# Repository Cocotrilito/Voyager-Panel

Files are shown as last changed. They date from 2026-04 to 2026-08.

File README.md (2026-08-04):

<div align="center">

# ⟡ VOYAGER PANEL ⟡

### An E-Ink travel dashboard

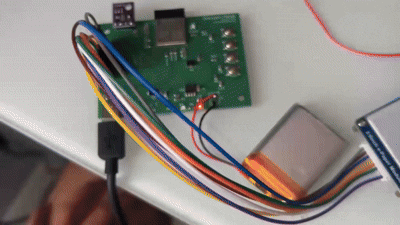
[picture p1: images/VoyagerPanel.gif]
Voyager Panel in motion


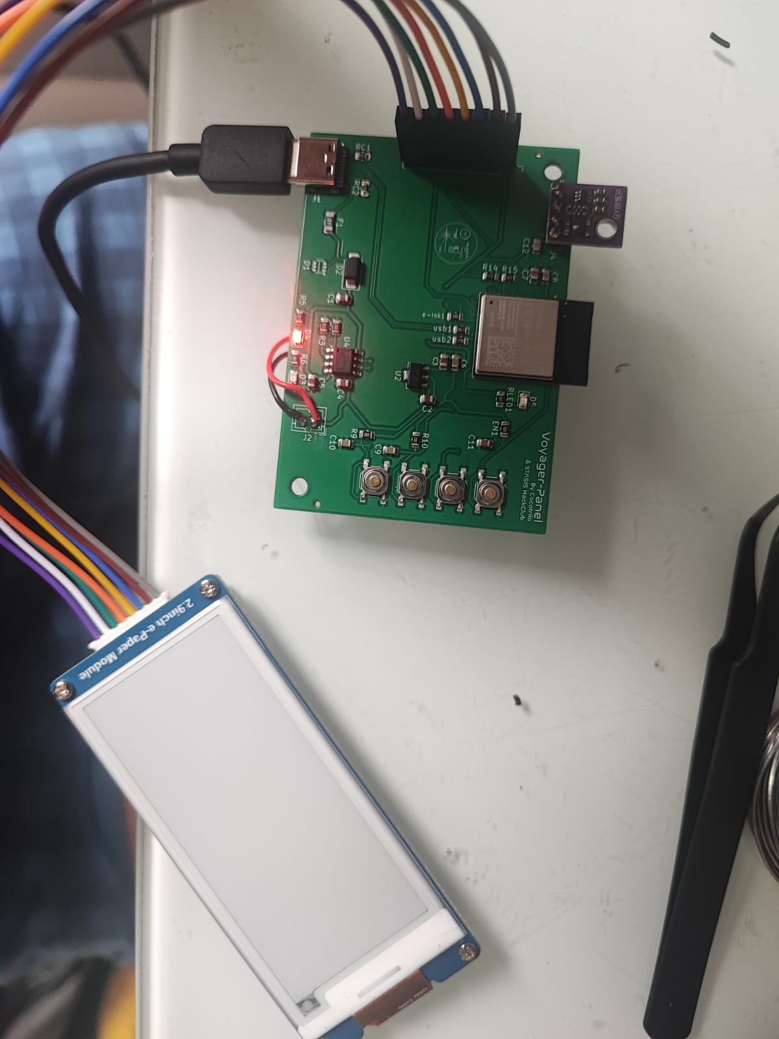
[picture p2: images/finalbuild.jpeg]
Final build


`ESP32-S3` · `296×128 E-Paper` · `Battery Powered` · `Wi-Fi` · `Low Power`

</div>

---

An E-Ink travel dashboard. with an ESP32-S3 Showing weather, hackclub countdowns, and travel info for hackactons. this dashboard has Low-Power consumption, Wi-Fi connected, battery-operated!!!!

---

## ⟡ The reason behind this project

This project started from the *dream* of always wanting to have a big countdown telling you the Narrow door for a better future is closing, yeah crazy right?, hahaha well actually this project started in the supermarket of my local city, I was shopping and noticed an E-Ink display, I thought *I have seen this before* and it was when I was searching my first project I saw something called E-Ink dashboard, and was cool but I thought Im too newbie for this, so I challenged myself to improve my PCB designer skills and I think I did a really cool project, im really proud of it tbh, well but in the end the actual big reason is to truly have a giant countdown telling you stasis is over in X days or telling you your youth days are over in X days I love presure >:D

---

## ⟡ Schematic Overview

<div align="center">

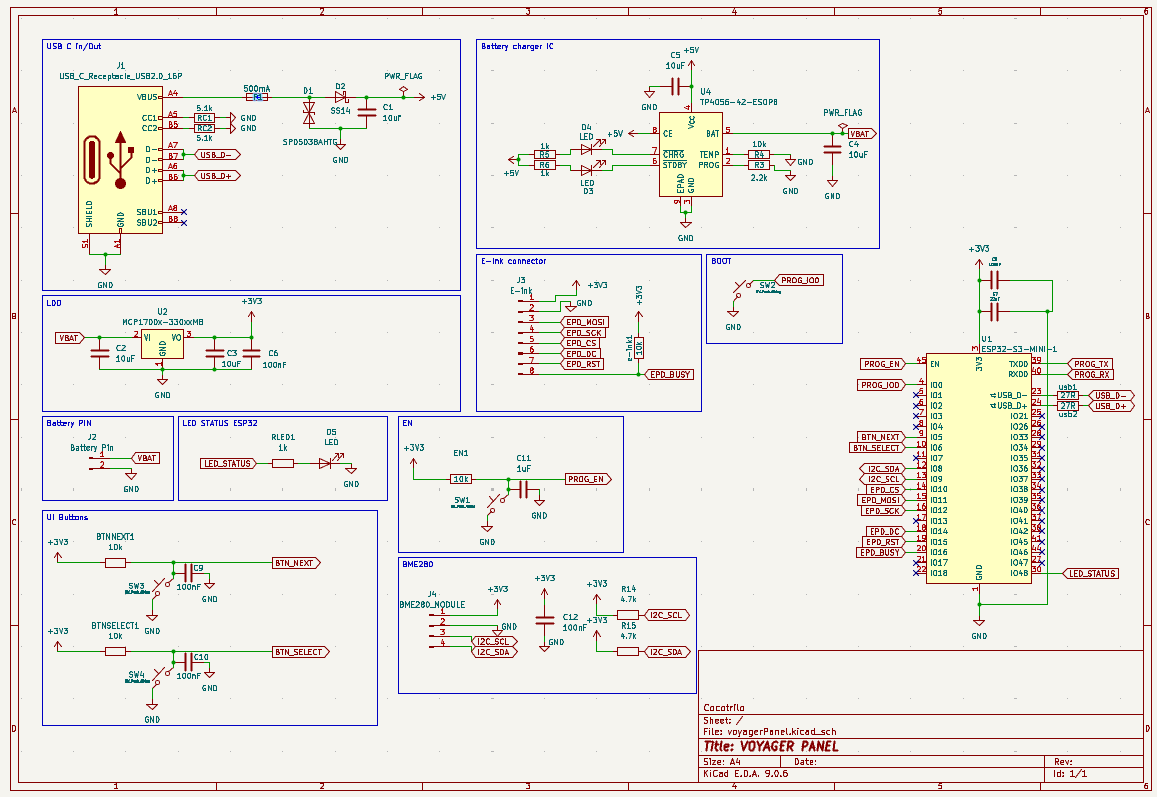
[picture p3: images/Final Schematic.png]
Schematic


</div>

---

## ⟡ PCB — DIFFERENT VERSIONS

<div align="center">

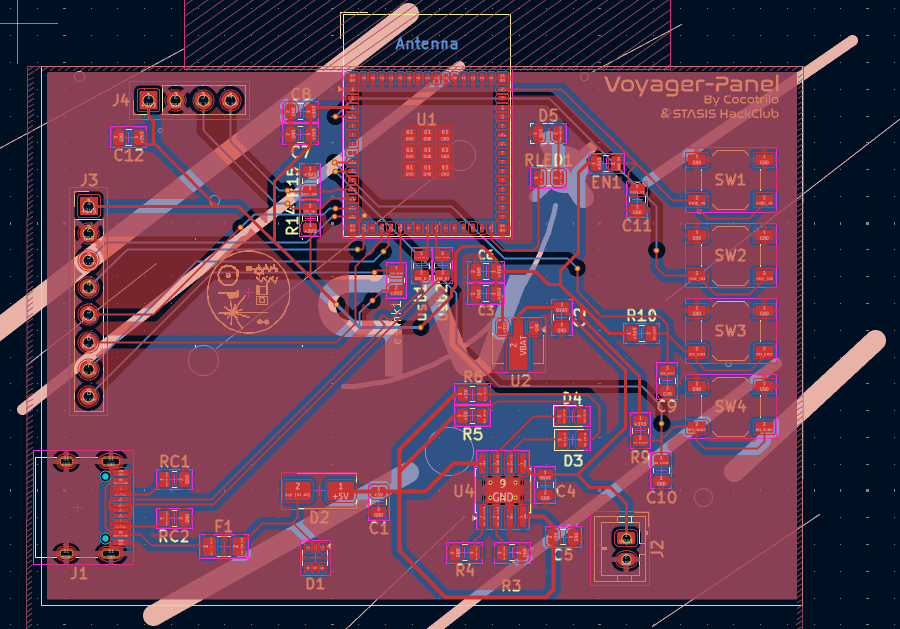
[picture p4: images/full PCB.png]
PCB


</div>

<table>
<tr>
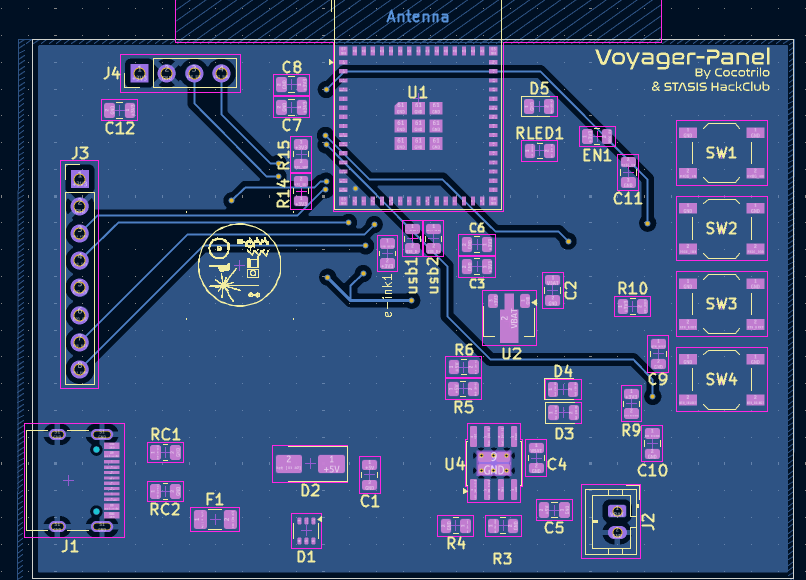
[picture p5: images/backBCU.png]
B.Cu layer
<td width="50%"></td>
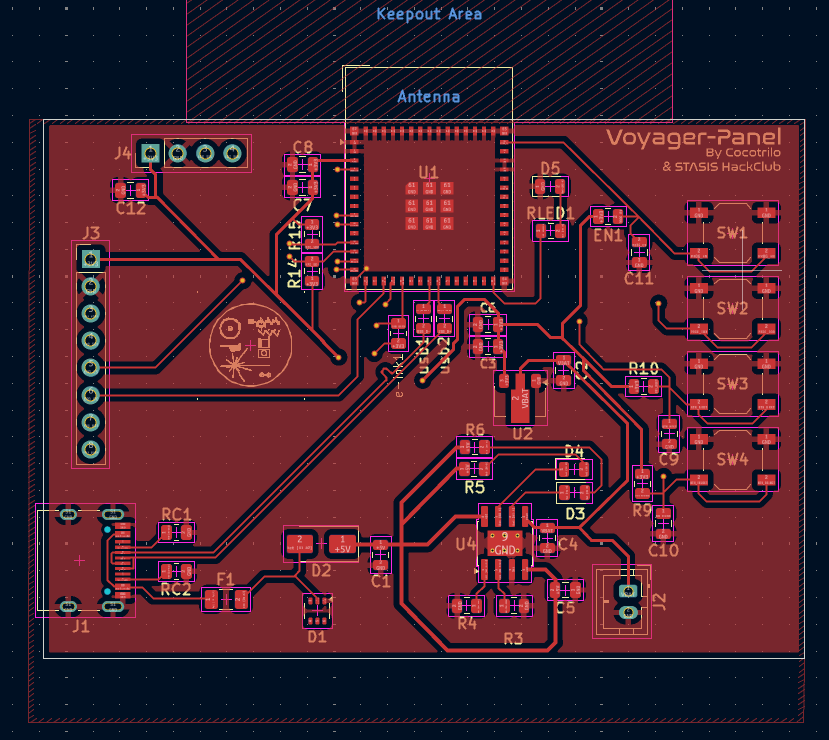
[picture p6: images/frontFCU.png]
F.Cu layer
<td width="50%"></td>
</tr>
<tr>
<td align="center"><b>Back copper</b></td>
<td align="center"><b>Front copper</b></td>
</tr>
</table>

---

## ⟡ RENDER!!

<div align="center">

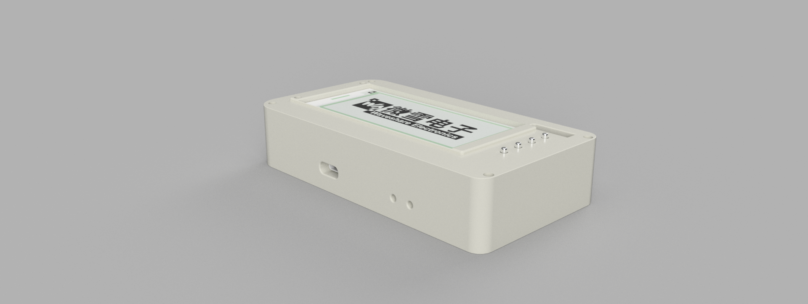
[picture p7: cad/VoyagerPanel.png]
RenderFusion


</div>

<table>
<tr>
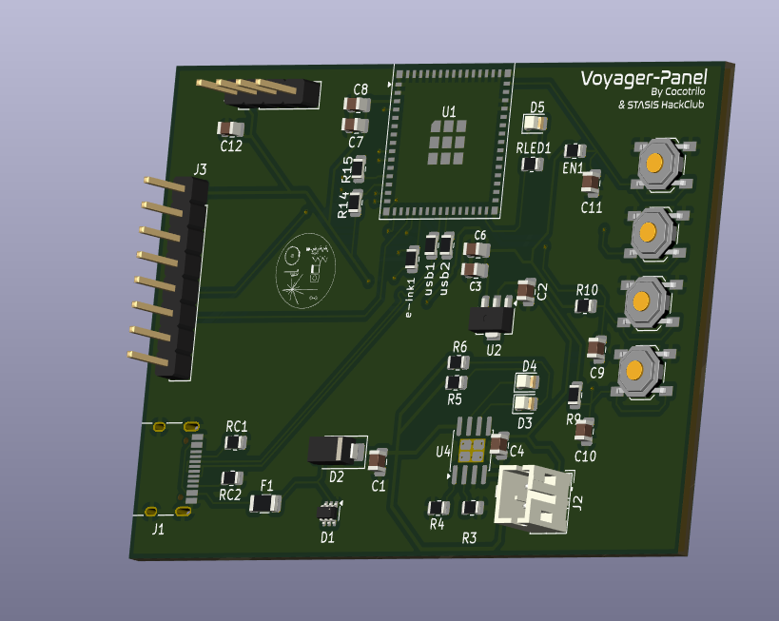
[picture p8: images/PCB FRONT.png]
PCB front
<td width="50%"></td>
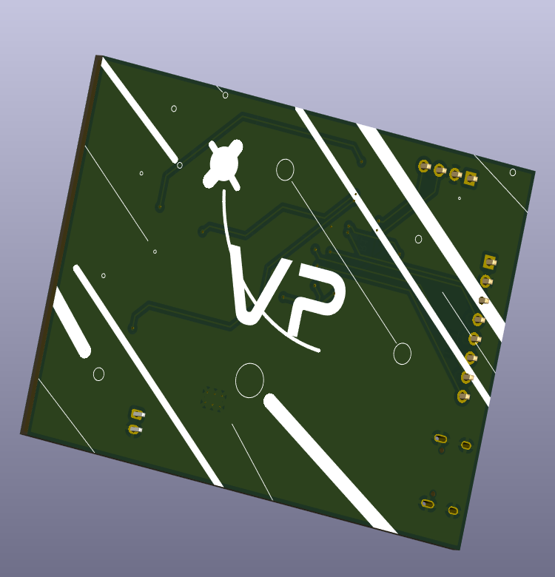
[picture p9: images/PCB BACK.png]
PCB back
<td width="50%"></td>
</tr>
<tr>
<td align="center"><b>Front</b></td>
<td align="center"><b>Back</b></td>
</tr>
</table>

---

## ⟡ Hardware at a glance

| | |
|---|---|
| **MCU** | ESP32-S3-MINI-1 — Wi-Fi, BLE, native USB |
| **Display** | Waveshare 2.9" e-Paper, 296×128, SSD1680 controller |
| **Sensor** | BMP280 over I2C — temperature, pressure, derived altitude |
| **Power** | 1000 mAh LiPo, TP4056 charger, MCP1700 LDO |
| **Protection** | TVS ESD array, Schottky reverse-current diode, 500 mA polyfuse |
| **Programming** | Native USB-C, no external UART bridge |

---

## ⟡ Firmware

Built with **PlatformIO** on the Arduino framework.

```
firmware/VoyagerPanelFirmware/
├── platformio.ini
└── src/
    ├── main.cpp
    └── images.h
```

Because the board uses the ESP32-S3's native USB and carries no USB-UART bridge,
`Serial` has to be routed to the USB CDC peripheral. Without these flags nothing
reaches the host:

```ini
build_flags =
    -D ARDUINO_USB_MODE=1
    -D ARDUINO_USB_CDC_ON_BOOT=1
```

The sensor and the display initialise **independently**, so a failure in one does not
take down the other. The dashboard degrades gracefully instead of hanging.

### Live telemetry

```
========== VOYAGER SENSOR ==========
  Temperature : 29.29 C
  Pressure    : 751.36 hPa
  Altitude    : 2452.2 m
====================================
```

---

## ⟡ Debugging log

The display refused to render, and tracking down why turned into the most interesting
part of this build — a full diagnosis of a hardware fault carried out **without a
multimeter**, using the microcontroller itself as the measuring instrument.

Short version: the SSD1680 was running on **phantom power**, leaking current through
its own ESD protection diodes. Enough to acknowledge a reset, not enough to execute a
single SPI command.

The full write-up, including the software continuity matrix used to prove it, lives in
**[DEBUGGING.md](DEBUGGING.md)**.

A second find along the way: the module sold as a BME280 is actually a **BMP280**. Its
chip ID register returns `0x58` instead of `0x60`, and it has no humidity channel. The
firmware reads that register and picks the right driver rather than trusting the label.

---

## ⟡ BOM

| Name | Purpose | Qty | Cost (USD) | Distributor |
|---|---|-----|---|---|
| ESP32-S3-MINI-1 | Main microcontroller with WiFi and USB native | 1 | $8.50 | AliExpress |
| Waveshare 2.9inch e-Paper Module | Main e-ink display 296x128px | 1 | $17.00 | AliExpress |
| BME280 Breakout Module | Temperature/Humidity/Pressure sensor | 1 | $5.15 | AliExpress |
| LiPo Battery 1000mAh 3.7V | Portable power source | 1 | $5.00 | Local Ecuador |
| USB-C Receptacle 16P | Power input and native USB programming | 1 | $0.50 | JLCPCB |
| JST PH 2mm 2-Pin Connector | Battery connector | 1 | $0.10 | JLCPCB |
| Pin Header 1x08 2.54mm | E-ink display connector | 1 | $0.05 | Local |
| Pin Header 1x04 2.54mm | BME280 module connector | 1 | $0.05 | Local |
| TP4056-42-ESOP8 | LiPo battery charger IC | 1 | $0.15 | JLCPCB |
| MCP1700-3302 SOT-89 | 3.3V LDO regulator 0.2V dropout | 1 | $0.45 | JLCPCB |
| SP0503BAHTG SOT-363 | TVS ESD protection diode for USB | 1 | $0.20 | JLCPCB |
| SS14 SMA | Schottky diode reverse current protection | 1 | $0.05 | JLCPCB |
| Polyfuse 500mA 1206 | Resettable overcurrent fuse | 1 | $0.10 | JLCPCB |
| SW_SPST_TL3342 | Tactile buttons Reset/Boot/Next/Select | 4 | $0.05 | JLCPCB |
| LED 0805 Red | Battery charging indicator CHRG | 1 | $0.02 | JLCPCB |
| LED 0805 Blue | Standby indicator STDBY | 1 | $0.02 | JLCPCB |
| LED 0805 Green | System status indicator | 1 | $0.02 | JLCPCB |
| Resistor 1k 0805 | LED current limiting resistors | 3 | $0.03 | JLCPCB |
| Resistor 2.2k 0805 | TP4056 charge current set 550mA | 1 | $0.01 | JLCPCB |
| Resistor 4.7k 0805 | I2C SDA/SCL pull-up resistors | 2 | $0.02 | JLCPCB |
| Resistor 5.1k 0805 | USB-C CC1/CC2 pull-down resistors | 2 | $0.02 | JLCPCB |
| Resistor 10k 0805 | Pull-ups for EN/BOOT/UI buttons | 5 | $0.05 | JLCPCB |
| Resistor 27R 0805 | USB D+/D- series termination | 2 | $0.02 | JLCPCB |
| Capacitor 100nF 0805 | High frequency decoupling | 5 | $0.05 | JLCPCB |
| Capacitor 1uF 0805 | EN pin reset debounce | 1 | $0.02 | JLCPCB |
| Capacitor 10uF 0805 | Bulk decoupling capacitors | 5 | $0.15 | JLCPCB |
| Capacitor 22uF 0805 | ESP32 main power bulk decoupling | 1 | $0.05 | JLCPCB |
| PCB + SMT Assembly | 2-layer PCB with PCBA | 1 | $47.90 | JLCPCB |
| **TOTAL** | | | **$85.42** | |

---

## ⟡ Repository layout

```
├── cad/                          Fusion 360 enclosure + renders
├── docs/references/              Datasheets and reference material
├── firmware/
│   ├── VoyagerPanelFirmware/     PlatformIO project
│   └── diagnostics/              Hardware bring-up test sketches
├── images/                       Schematic, PCB, and build photos
├── projectFiles/
├── voyagerPanel/                 KiCad project
├── DEBUGGING.md
└── README.md
```

---

## ⟡ Final notes!

Thanks for reading! made possible with http://stasis.hackclub.com/

---

<div align="center">

## ⟡ me

*By cocotrilo*

**made with luv (THIS ONE was with a lot of love, EXCEPT FOR THE BOM PLEASE DONT USE EVER ALIEXPRESS) Nk but luv from EC <3**

</div>

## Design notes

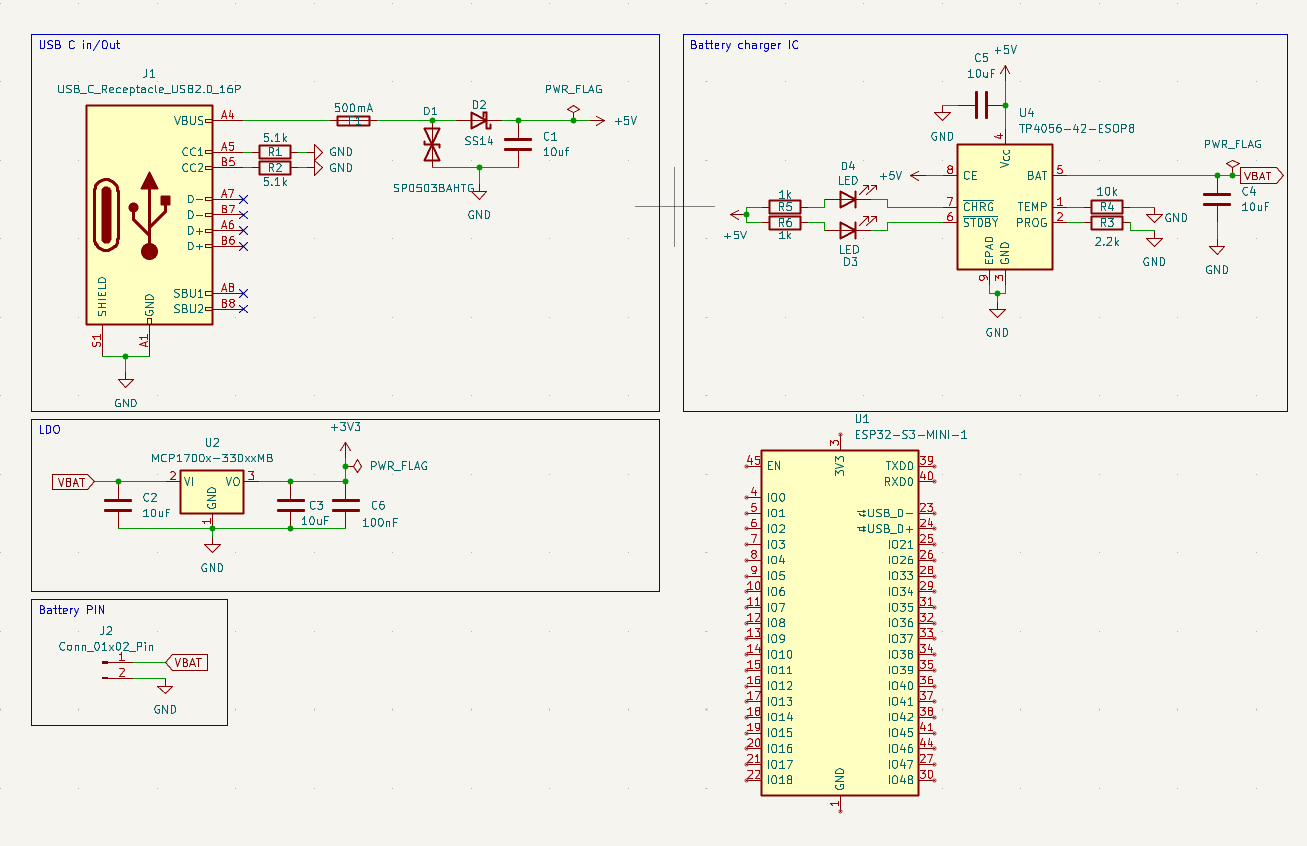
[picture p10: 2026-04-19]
images/Day 1 schematic.png

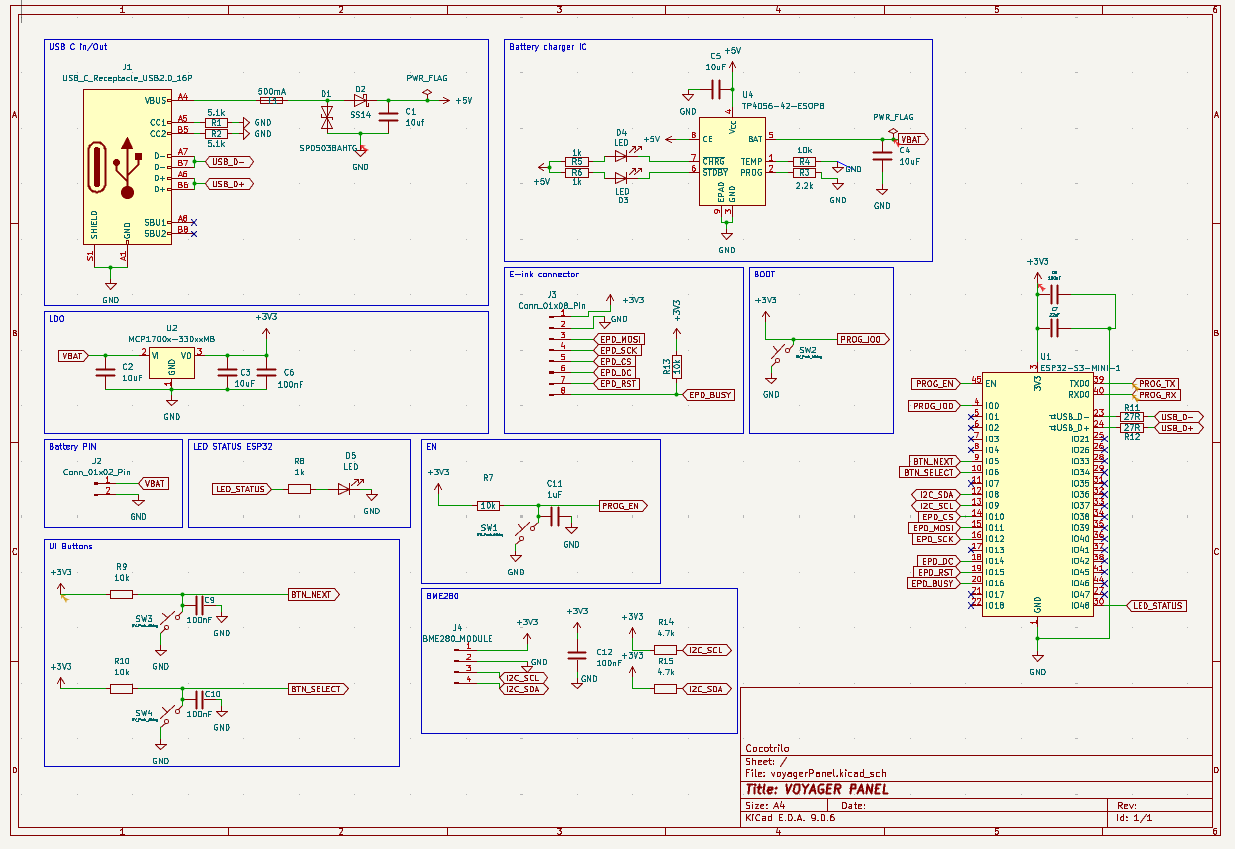
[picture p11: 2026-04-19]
images/Day Schematic.png

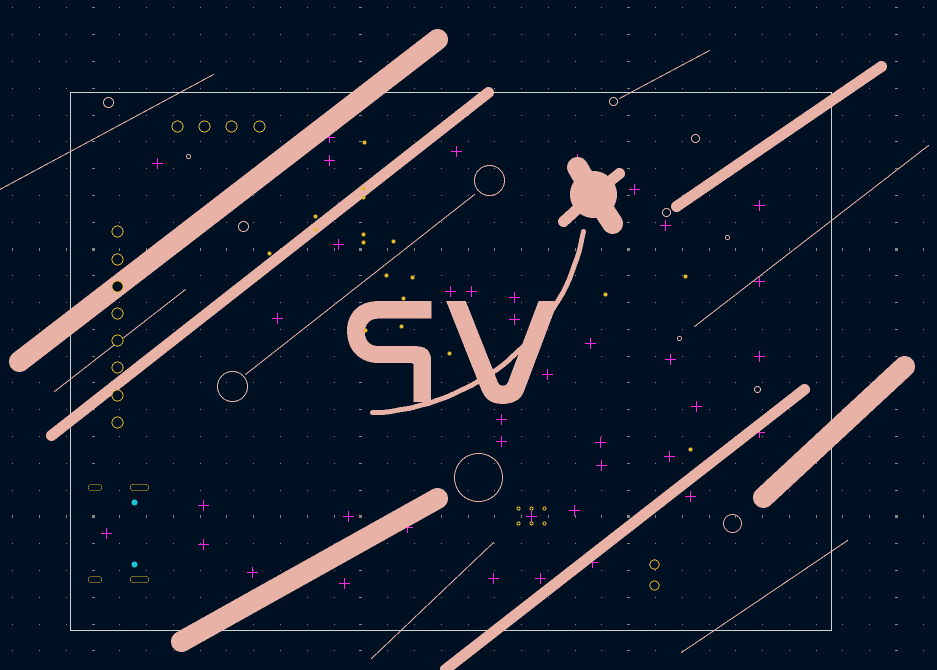
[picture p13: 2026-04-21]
images/back.png

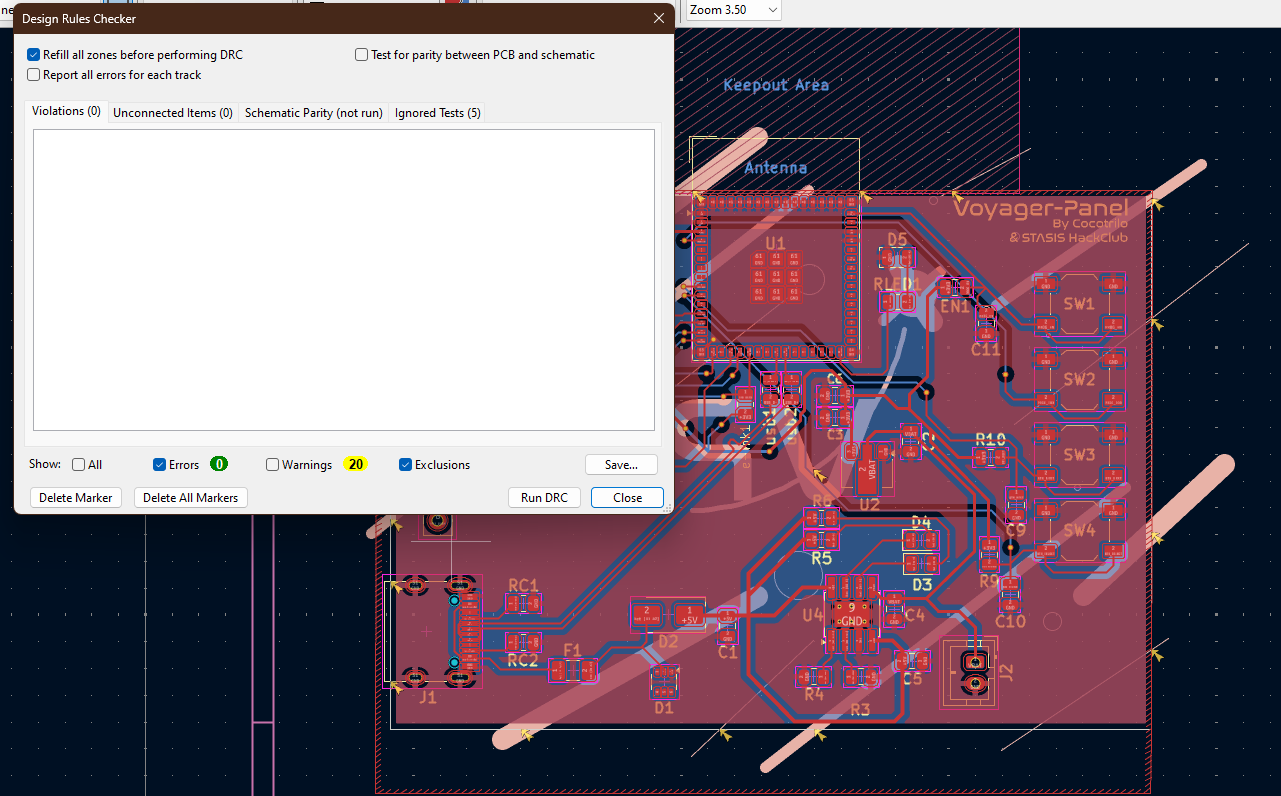
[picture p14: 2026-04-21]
images/DRC.png

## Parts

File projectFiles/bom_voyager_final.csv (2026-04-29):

Name | Purpose | Quantity | Unit Cost (USD) | Total Cost (USD) | Distributor | Link
ESP32-S3-MINI-1 | Main microcontroller with WiFi and USB native | 1 | $8.50 | $8.50 | AliExpress | https://www.aliexpress.com/item/ESP32-S3-MINI-1.html
Waveshare 2.9inch e-Paper Module | Main e-ink display 296x128px | 1 | $17.00 | $17.00 | AliExpress | https://www.waveshare.com/2.9inch-e-paper-module.htm
BME280 Breakout Module | Temperature/Humidity/Pressure sensor | 1 | $5.15 | $5.15 | AliExpress | https://www.aliexpress.us/item/3256805961500122.html
LiPo Battery 1000mAh 3.7V | Portable power source - bought locally | 1 | $5.00 | $5.00 | Local Ecuador | N/A
USB-C Receptacle 16P | Power input and native USB programming | 1 | $0.50 | $0.50 | JLCPCB/LCSC | https://www.lcsc.com/product-detail/C165948.html
JST PH 2mm 2-Pin Connector | Battery connector | 1 | $0.10 | $0.10 | JLCPCB/LCSC | https://www.lcsc.com/product-detail/C295747.html
Pin Header 1x08 2.54mm | E-ink display connector | 1 | $0.05 | $0.05 | Local/AliExpress | N/A
Pin Header 1x04 2.54mm | BME280 module connector | 1 | $0.05 | $0.05 | Local/AliExpress | N/A
TP4056-42-ESOP8 | LiPo battery charger IC up to 550mA | 1 | $0.15 | $0.15 | JLCPCB/LCSC | https://www.lcsc.com/product-detail/C16581.html
MCP1700-3302 SOT-89 | 3.3V LDO regulator 0.2V dropout | 1 | $0.45 | $0.45 | JLCPCB/LCSC | https://www.lcsc.com/product-detail/C5446.html
SP0503BAHTG SOT-363 | TVS ESD protection diode for USB | 1 | $0.20 | $0.20 | JLCPCB/LCSC | https://www.lcsc.com/product-detail/C558442.html
SS14 SMA | Schottky diode reverse current protection | 1 | $0.05 | $0.05 | JLCPCB/LCSC | https://www.lcsc.com/product-detail/C2480.html
Polyfuse 500mA 1206 | Resettable overcurrent fuse | 1 | $0.10 | $0.10 | JLCPCB/LCSC | https://www.lcsc.com/product-detail/C69688.html
SW_SPST_TL3342 x4 | Tactile buttons - Reset/Boot/Next/Select | 4 | $0.05 | $0.20 | JLCPCB/LCSC | https://www.lcsc.com/product-detail/C2886894.html
LED 0805 Red | Battery charging indicator (CHRG) | 1 | $0.02 | $0.02 | JLCPCB/LCSC | https://www.lcsc.com/product-detail/C84256.html
LED 0805 Blue | Standby indicator (STDBY) | 1 | $0.02 | $0.02 | JLCPCB/LCSC | https://www.lcsc.com/product-detail/C72041.html
LED 0805 Green | System status indicator | 1 | $0.02 | $0.02 | JLCPCB/LCSC | https://www.lcsc.com/product-detail/C72043.html
Resistor 1k 0805 x3 | LED current limiting resistors | 3 | $0.01 | $0.03 | JLCPCB/LCSC | https://www.lcsc.com/product-detail/C17513.html
Resistor 2.2k 0805 | TP4056 charge current set (~550mA) | 1 | $0.01 | $0.01 | JLCPCB/LCSC | https://www.lcsc.com/product-detail/C17520.html
Resistor 4.7k 0805 x2 | I2C SDA/SCL pull-up resistors | 2 | $0.01 | $0.02 | JLCPCB/LCSC | https://www.lcsc.com/product-detail/C17673.html
Resistor 5.1k 0805 x2 | USB-C CC1/CC2 pull-down resistors | 2 | $0.01 | $0.02 | JLCPCB/LCSC | https://www.lcsc.com/product-detail/C23186.html
Resistor 10k 0805 x5 | Pull-ups for EN/BOOT/UI buttons | 5 | $0.01 | $0.05 | JLCPCB/LCSC | https://www.lcsc.com/product-detail/C17414.html
Resistor 27R 0805 x2 | USB D+/D- series termination resistors | 2 | $0.01 | $0.02 | JLCPCB/LCSC | https://www.lcsc.com/product-detail/C17719.html
Capacitor 100nF 0805 x5 | High frequency decoupling capacitors | 5 | $0.01 | $0.05 | JLCPCB/LCSC | https://www.lcsc.com/product-detail/C49678.html
Capacitor 1uF 0805 | EN pin reset debounce capacitor | 1 | $0.02 | $0.02 | JLCPCB/LCSC | https://www.lcsc.com/product-detail/C28323.html
Capacitor 10uF 0805 x5 | Bulk decoupling capacitors | 5 | $0.03 | $0.15 | JLCPCB/LCSC | https://www.lcsc.com/product-detail/C15850.html
Capacitor 22uF 0805 | ESP32 main power bulk decoupling | 1 | $0.05 | $0.05 | JLCPCB/LCSC | https://www.lcsc.com/product-detail/C45783.html
PCB Manufacturing x5 | Custom 2-layer PCB with SMT assembly | 1 | $47.90 | $47.90 | JLCPCB | https://jlcpcb.com
TOTAL |  |  |  | ~$85.42

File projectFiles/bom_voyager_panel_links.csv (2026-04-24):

Name | Purpose | Quantity | Unit Cost (USD) | Total Cost (USD) | Distributor | Link
ESP32-S3-MINI-1 | Main microcontroller with WiFi | 1 | $8.5 | $8.5 | LCSC | https://www.lcsc.com/product-detail/C2913202.html
Waveshare 4.2inch e-Paper Module | Main e-ink display 400x300px | 1 | $18.00 | $18.00 | Waveshare | https://www.waveshare.com/4.2inch-e-paper-module.htm
BME280 Breakout Module | Temperature/Humidity/Pressure sensor | 1 | $5.15 | $5.15 | AliExpress | https://www.aliexpress.us/item/3256805961500122.html?mp=1
LiPo Battery 1000mAh 3.7V | Portable power source | 1 | $5.00 | $5.00 | AliExpress
USB-C Receptacle 16P | Power input and native USB programming | 1 | $0.50 | $0.50 | LCSC | https://www.lcsc.com/product-detail/C165948.html
JST PH 2mm 2-Pin Connector | Battery connector | 1 | $0.10 | $0.10 | LCSC | https://www.lcsc.com/product-detail/C295747.html
Pin Header 1x08 2.54mm | E-ink display connector | 1 | $0.05 | $0.05 | LCSC | https://www.lcsc.com/product-detail/C2337.html
Pin Header 1x04 2.54mm | BME280 module connector | 1 | $0.03 | $0.03 | LCSC | https://www.lcsc.com/product-detail/C2336.html
TP4056-42-ESOP8 | LiPo battery charger IC | 1 | $0.15 | $0.15 | LCSC | https://www.lcsc.com/product-detail/C16581.html
MCP1700-3302 SOT-89 | 3.3V LDO regulator 0.2V dropout | 1 | $0.45 | $0.45 | LCSC | https://www.lcsc.com/product-detail/C5446.html
SP0503BAHTG SOT-363 | TVS ESD protection diode | 1 | $0.20 | $0.20 | LCSC | https://www.lcsc.com/product-detail/C558442.html
SS14 SMA | Schottky reverse protection diode | 1 | $0.05 | $0.05 | LCSC | https://www.lcsc.com/product-detail/C2480.html
Polyfuse 500mA 1206 | Resettable overcurrent fuse | 1 | $0.10 | $0.10 | LCSC | https://www.lcsc.com/product-detail/C69688.html
SW_SPST_TL3342 x4 | Tactile push buttons (Reset/Boot/Next/Select) | 4 | $0.05 | $0.20 | LCSC | https://www.lcsc.com/product-detail/C2886894.html
LED 0805 Red | Battery charging indicator | 1 | $0.02 | $0.02 | LCSC | https://www.lcsc.com/product-detail/C84256.html
LED 0805 Blue | Standby indicator | 1 | $0.02 | $0.02 | LCSC | https://www.lcsc.com/product-detail/C72041.html
LED 0805 Green | System status indicator | 1 | $0.02 | $0.02 | LCSC | https://www.lcsc.com/product-detail/C72043.html
Resistor 1k 0805 x3 | LED current limiting | 3 | $0.01 | $0.03 | LCSC | https://www.lcsc.com/product-detail/C17513.html
Resistor 2.2k 0805 | TP4056 charge current set | 1 | $0.01 | $0.01 | LCSC | https://www.lcsc.com/product-detail/C17520.html
Resistor 4.7k 0805 x2 | I2C SDA/SCL pull-ups | 2 | $0.01 | $0.02 | LCSC | https://www.lcsc.com/product-detail/C17673.html
Resistor 5.1k 0805 x2 | USB-C CC1/CC2 pull-downs | 2 | $0.01 | $0.02 | LCSC | https://www.lcsc.com/product-detail/C23186.html
Resistor 10k 0805 x5 | Pull-ups EN/BOOT/buttons | 5 | $0.01 | $0.05 | LCSC | https://www.lcsc.com/product-detail/C17414.html
Resistor 27R 0805 x2 | USB D+/D- series resistors | 2 | $0.01 | $0.02 | LCSC | https://www.lcsc.com/product-detail/C17719.html
Capacitor 100nF 0805 x5 | Decoupling capacitors | 5 | $0.01 | $0.05 | LCSC | https://www.lcsc.com/product-detail/C49678.html
Capacitor 1uF 0805 | EN pin debounce | 1 | $0.02 | $0.02 | LCSC | https://www.lcsc.com/product-detail/C28323.html
Capacitor 10uF 0805 x5 | Bulk decoupling | 5 | $0.03 | $0.15 | LCSC | https://www.lcsc.com/product-detail/C15850.html
Capacitor 22uF 0805 | ESP32 main bulk decoupling | 1 | $0.05 | $0.05 | LCSC | https://www.lcsc.com/product-detail/C45783.html
PCB Manufacturing x5 | Custom 2-layer PCB 70x50mm | 5 | $5.00 | $5.00 | JLCPCB | https://jlcpcb.com
PCB Assembly PCBA | SMT assembly for SMD components | 1 | $17.00 | $17.00 | JLCPCB | https://jlcpcb.com
TOTAL |  |  |  | $59-62

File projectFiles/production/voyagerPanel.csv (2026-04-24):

Id | Designator | Footprint | Quantity | Comment | Supplier and ref
1 | C3,C4,C2,C5 | C_0805_2012Metric | 4 | 10uF
2 | R6,R5,RLED1 | R_0805_2012Metric | 3 | 1k
3 | F1 | Fuse_1206_3216Metric | 1 | 500mA
4 | J3 | PinHeader_1x08_P2.54mm_Vertical | 1 | E-ink
5 | RC2,RC1 | R_0805_2012Metric | 2 | 5.1k
6 | SW3,SW4,SW2,SW1 | SW_SPST_TL3342 | 4 | SW_Push_45deg
7 | C1 | C_0805_2012Metric | 1 | 10uf
8 | C7 | C_0805_2012Metric | 1 | 22uF
9 | C11 | C_0805_2012Metric | 1 | 1uF
10 | D5,D4,D3 | LED_0805_2012Metric | 3 | LED
11 | R9,R4,R10,e-ink1,EN1 | R_0805_2012Metric | 5 | 10k
12 | J1 | USB_C_Receptacle_HRO_TYPE-C-31-M-12 | 1 | USB_C_Receptacle_USB2.0_16P
13 | C9,C8,C12,C10,C6 | C_0805_2012Metric | 5 | 100nF
14 | usb1,usb2 | R_0805_2012Metric | 2 | 27R
15 | D2 | D_SMA | 1 | SS14
16 | U4 | SOIC-8-1EP_3.9x4.9mm_P1.27mm_EP2.41x3.3mm_ThermalVias | 1 | TP4056-42-ESOP8
17 | J2 | JST_PH_B2B-PH-K_1x02_P2.00mm_Vertical | 1 | Battery Pin
18 | U2 | SOT-89-3 | 1 | MCP1700x-330xxMB
19 | J4 | PinHeader_1x04_P2.54mm_Vertical | 1 | BME280_MODULE
20 | R3 | R_0805_2012Metric | 1 | 2.2k
21 | R14,R15 | R_0805_2012Metric | 2 | 4.7k
22 | D1 | SOT-363_SC-70-6 | 1 | SP0503BAHTG
23 | U1 | ESP32-S2-MINI-1 | 1 | ESP32-S3-MINI-1

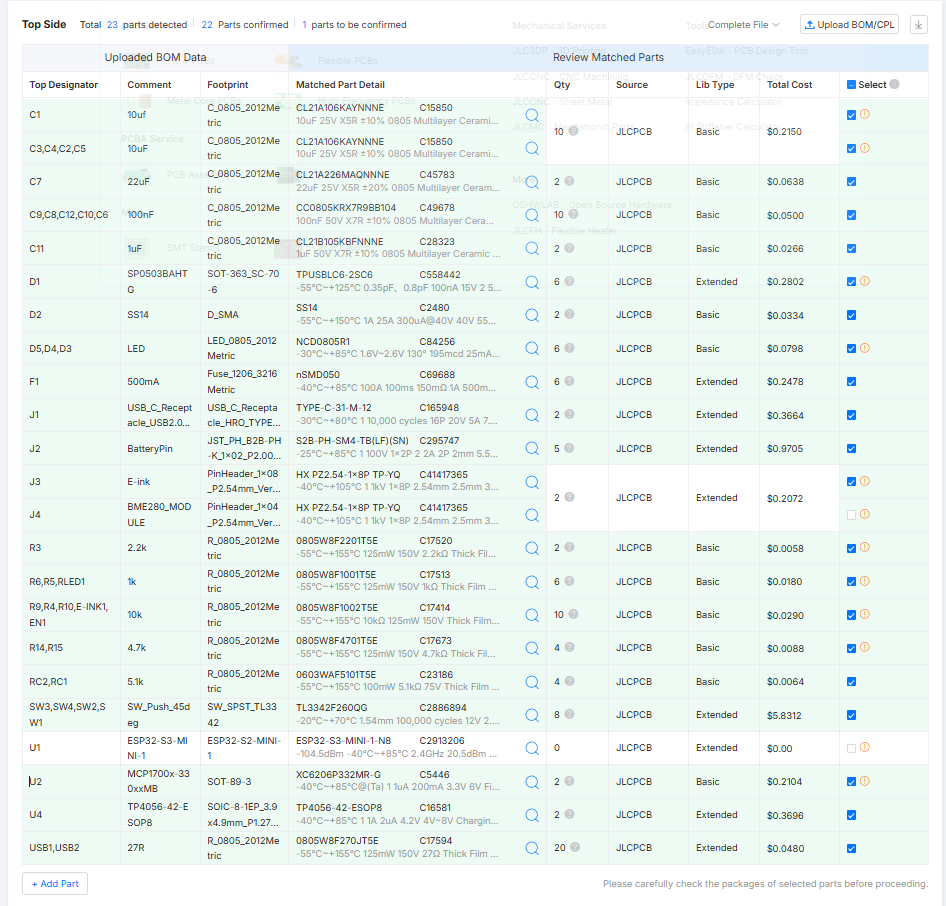
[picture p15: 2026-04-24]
images/BOM JLCPCB.png

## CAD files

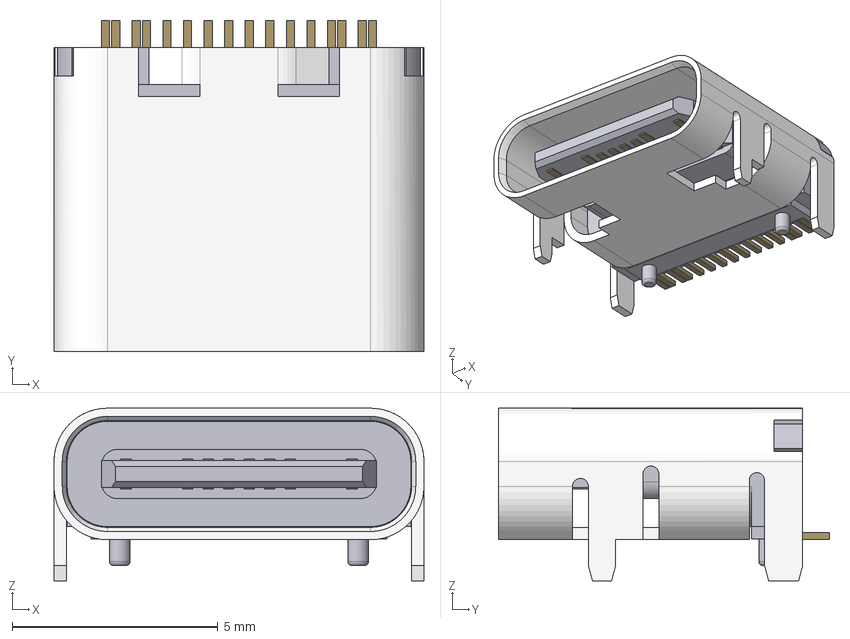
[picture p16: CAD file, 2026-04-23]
cad/MODELS/16-pin-smd-usb-c-connector-through-holes-1.snapshot.7/usb-c_16pins_vertical.step
9.00 x 8.05 x 4.20 mm
tongue
shield
contact_001
contact_002
contact_003
contact_004
contact_court_001
contact_court_002
contact_court_003
contact_court_004
contact_005
contact_006
contact_007
contact_008
contact_court_005
contact_court_006
contact_court_007
contact_court_008
pin_001
pin_002
pin_003
pin_004
pin_005
pin_006
pin_007
pin_008
pin_009
pin_010
pin_011
pin_012
pin_013
pin_014
pin_015
pin_016

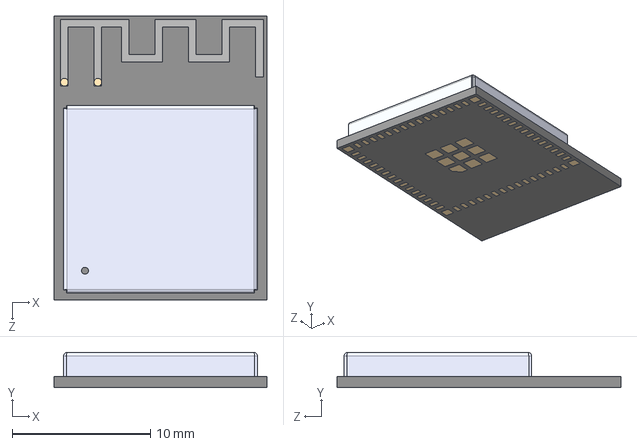
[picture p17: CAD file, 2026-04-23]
cad/MODELS/ESP32_S3_MINI_1_N8/ESP32-S3-MINI-1-N8.STEP
15.4 x 2.55 x 20.5 mm

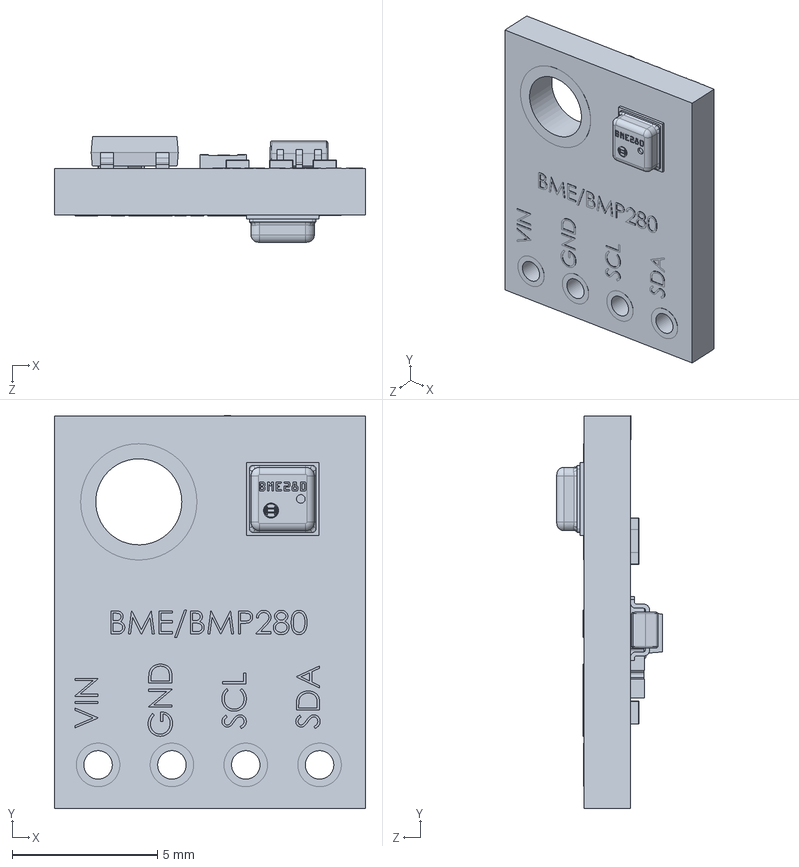
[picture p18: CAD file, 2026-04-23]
cad/MODELS/gy-bme280-1.snapshot.4/GY-BME280.SLDPRT
10.7 x 13.5 x 3.63 mm

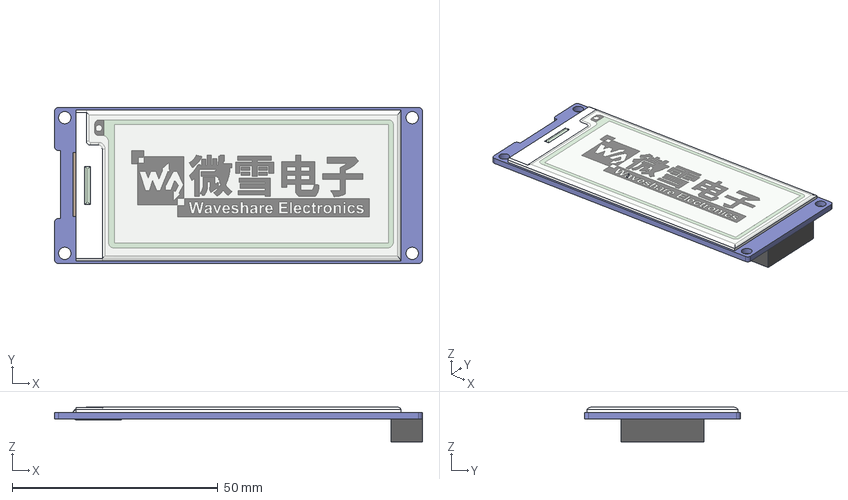
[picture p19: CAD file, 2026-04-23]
cad/MODELS/waveshare-2-9-e-paper-module-1.snapshot.1/Waveshare 2.9 epaper module.step
89.5 x 38.0 x 8.47 mm
pcb
Waveshare 2.9 E-ink - Display Folded v1

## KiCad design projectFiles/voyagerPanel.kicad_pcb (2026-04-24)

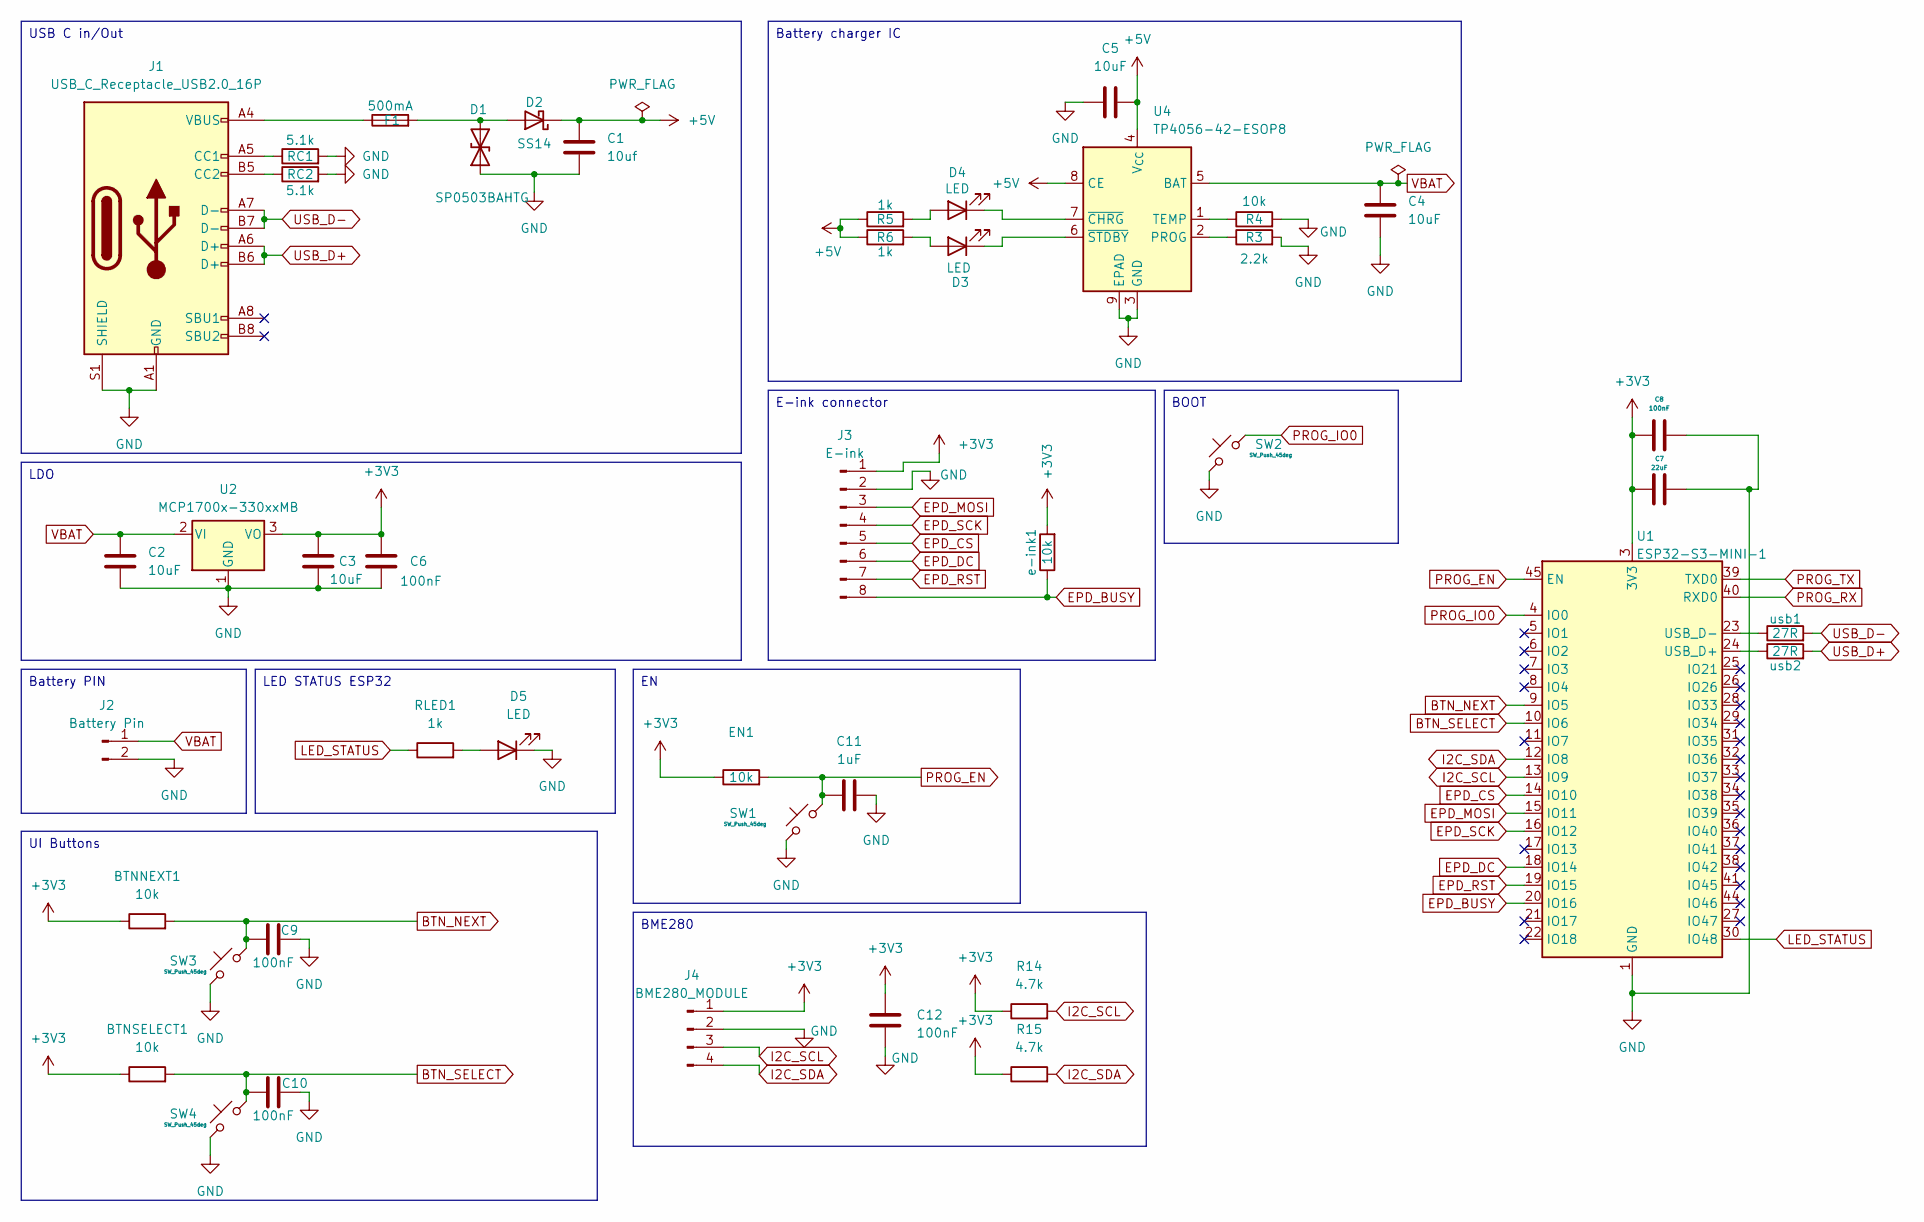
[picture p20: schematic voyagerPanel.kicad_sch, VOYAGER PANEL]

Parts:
BTNNEXT1: 10k; R_0805_2012Metric
BTNSELECT1: 10k; R_0805_2012Metric
C1: 10uf; C_0805_2012Metric
C2, C3, C4, C5: 10uF; C_0805_2012Metric
C6, C8, C9, C10, C12: 100nF; C_0805_2012Metric
C7: 22uF; C_0805_2012Metric
C11: 1uF; C_0805_2012Metric
D1: SP0503BAHTG; SOT-363_SC-70-6
D2: SS14; D_SMA
D3, D4, D5: LED; LED_0805_2012Metric
EN1: 10k; R_0805_2012Metric
F1: 500mA; Fuse_1206_3216Metric
J1: USB_C_Receptacle_USB2.0_16P; USB_C_Receptacle_HRO_TYPE-C-31-M-12
J2: Battery Pin; JST_PH_B2B-PH-K_1x02_P2.00mm_Vertical
J3: E-ink; PinHeader_1x08_P2.54mm_Vertical
J4: BME280_MODULE; PinHeader_1x04_P2.54mm_Vertical
R3: 2.2k; R_0805_2012Metric
R4: 10k; R_0805_2012Metric
R5, R6: 1k; R_0805_2012Metric
R14, R15: 4.7k; R_0805_2012Metric
RC1, RC2: 5.1k; R_0805_2012Metric
RLED1: 1k; R_0805_2012Metric
SW1, SW2, SW3, SW4: SW_Push_45deg; SW_SPST_TL3342
U1: ESP32-S3-MINI-1; ESP32-S2-MINI-1
U2: MCP1700x-330xxMB; SOT-89-3
U4: TP4056-42-ESOP8; SOIC-8-1EP_3.9x4.9mm_P1.27mm_EP2.41x3.3mm_ThermalVias
e-ink1: 10k; R_0805_2012Metric
usb1, usb2: 27R; R_0805_2012Metric

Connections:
+3V3: BTNNEXT1.1, BTNSELECT1.1, C3.1, C6.1, C7.1, C8.1, C12.1, EN1.1, J3.1, J4.1, R14.1, R15.1, U1.3 (3V3), U2.3 (VO), e-ink1.2; also elsewhere on the board
+5V: C1.1, C5.2, D2.1 (K), R5.1, R6.1, U4.4 (V_{CC}), U4.8 (CE)
BTN_NEXT: BTNNEXT1.2, C9.1, SW3.2, U1.9 (IO5); also elsewhere on the board
BTN_SELECT: BTNSELECT1.2, C10.1, SW4.2, U1.10 (IO6); also elsewhere on the board
EPD_BUSY: J3.8, U1.20 (IO16), e-ink1.1
EPD_CS: J3.5, U1.14 (IO10)
EPD_DC: J3.6, U1.18 (IO14)
EPD_MOSI: J3.3, U1.15 (IO11)
EPD_RST: J3.7, U1.19 (IO15)
EPD_SCK: J3.4, U1.16 (IO12)
GND: C1.2, C2.2, C3.2, C4.2, C5.1, C6.2, C7.2, C8.2, C9.2, C10.2, C11.1, C12.2, D1.1 (A1), D5.1 (K), J1.A1 (GND), J1.A12 (GND), J1.B1 (GND), J1.B12 (GND), J1.S1 (SHIELD), J2.2, J3.2, J4.2, R3.2, R4.2, RC1.2, RC2.2, SW1.1, SW2.1, SW3.1, SW4.1, U1.1 (GND), U1.2 (GND), U1.42 (GND), U1.43 (GND), U1.46 (GND), U1.47 (GND), U1.48 (GND), U1.49 (GND), U1.50 (GND), U1.51 (GND), U1.52 (GND), U1.53 (GND), U1.54 (GND), U1.55 (GND), U1.56 (GND), U1.57 (GND), U1.58 (GND), U1.59 (GND), U1.60 (GND), U1.61 (GND), U1.62 (GND), U1.63 (GND), U1.64 (GND), U1.65 (GND), U2.1 (GND), U4.3 (GND), U4.9 (EPAD)
I2C_SCL: J4.3, R14.2, U1.13 (IO9)
I2C_SDA: J4.4, R15.2, U1.12 (IO8)
LED_STATUS: RLED1.1, U1.30 (IO48)
unnamed: D1.2 (A2), D2.2 (A), F1.2
unnamed: D3.2 (A), R6.2
unnamed: D3.1 (K), U4.6 (~STDBY)
unnamed: D4.2 (A), R5.2
unnamed: D4.1 (K), U4.7 (~CHRG)
unnamed: D5.2 (A), RLED1.2
unnamed: F1.1, J1.A4 (VBUS), J1.A9 (VBUS), J1.B4 (VBUS), J1.B9 (VBUS)
unnamed: J1.A5 (CC1), RC1.1
unnamed: J1.B5 (CC2), RC2.1
unnamed: U1.24 (USB_D+), usb2.1
unnamed: U1.23 (USB_D-), usb1.1
unnamed: R3.1, U4.2 (PROG)
unnamed: R4.1, U4.1 (TEMP)
PROG_EN: C11.2, EN1.2, SW1.2, U1.45 (EN)
PROG_IO0: SW2.2, U1.4 (IO0)
PROG_RX: U1.40 (RXD0)
PROG_TX: U1.39 (TXD0)
USB_D+: J1.A6 (D+), J1.B6 (D+), usb2.2
USB_D-: J1.A7 (D-), J1.B7 (D-), usb1.2
VBAT: C2.1, C4.1, J2.1, U2.2 (VI), U4.5 (BAT)

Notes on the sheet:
Battery PIN
LDO
E-ink connector
UI Buttons
Battery charger IC
BOOT
USB C in/Out
BME280
LED STATUS ESP32

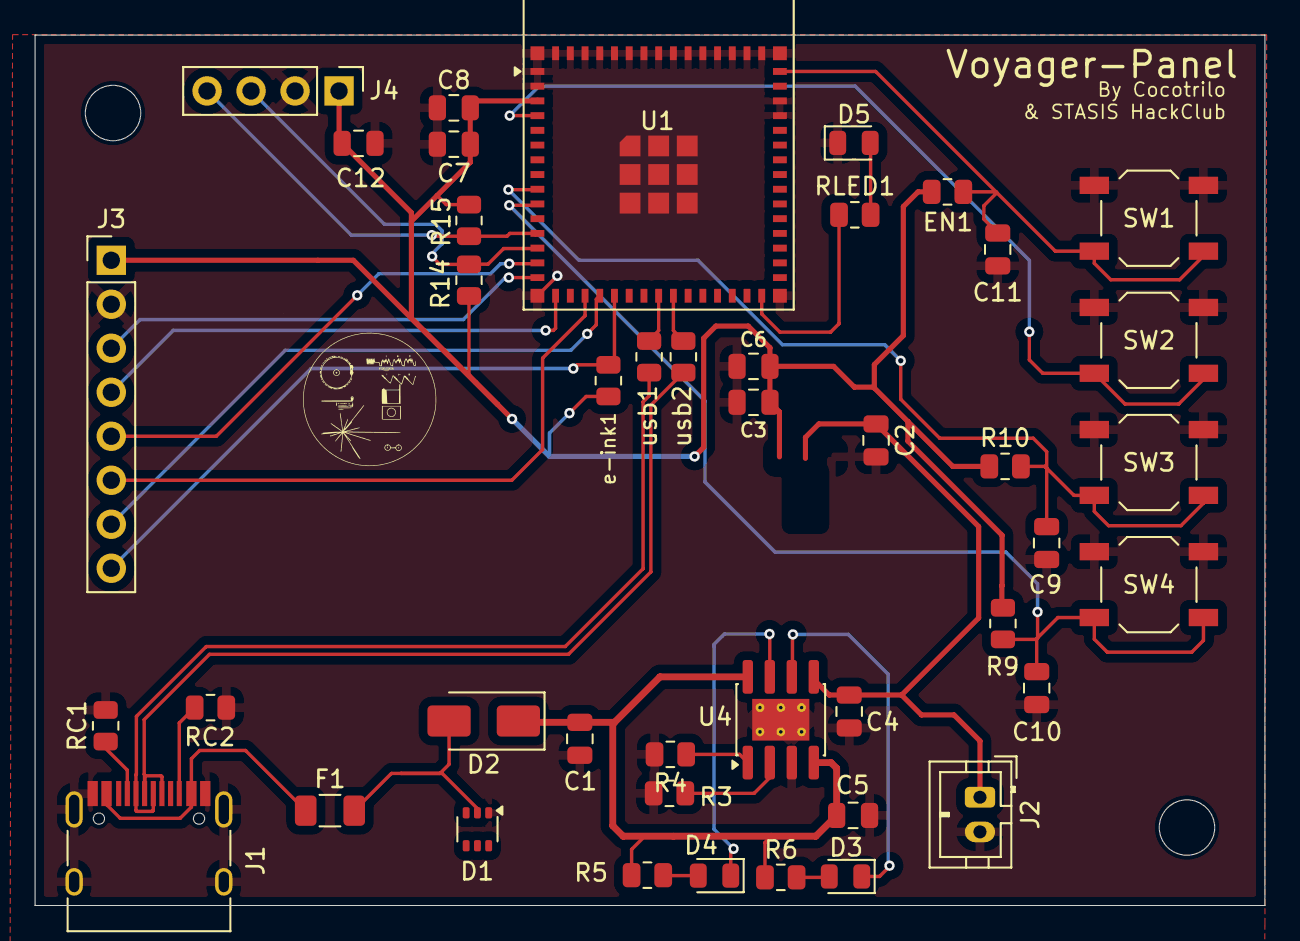
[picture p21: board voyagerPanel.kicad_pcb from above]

Board: 2 copper layers, 71.0 x 50.3 mm, 44 parts (1 on the bottom side), 32 nets.

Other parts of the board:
R9, R10: 10k; R_0805_2012Metric

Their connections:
+3V3: R9.1, R10.1; also elsewhere on the board
BTN_NEXT: R10.2; also elsewhere on the board
BTN_SELECT: R9.2; also elsewhere on the board

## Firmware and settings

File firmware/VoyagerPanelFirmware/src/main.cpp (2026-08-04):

#include <Arduino.h>
#include <Wire.h>
#include <SPI.h>
#include <Adafruit_BMP280.h>
#include <GxEPD2_BW.h>
#include <Fonts/FreeMonoBold9pt7b.h>
#include "images.h"

// pins for more info look into the schmeatic in the github
static const int PIN_LED    = 48;
static const int PIN_SDA    = 8;
static const int PIN_SCL    = 9;
static const int PIN_EPD_CS   = 10;
static const int PIN_EPD_MOSI = 11;
static const int PIN_EPD_SCK  = 12;
static const int PIN_EPD_DC   = 14;
static const int PIN_EPD_RST  = 15;
static const int PIN_EPD_BUSY = 16;
static const uint8_t SENSOR_ADDR = 0x76;
static const float   SEA_LEVEL_HPA = 1013.25f; 

Adafruit_BMP280 sensor;
GxEPD2_BW<GxEPD2_290_T94_V2, GxEPD2_290_T94_V2::HEIGHT>
    display(GxEPD2_290_T94_V2(PIN_EPD_CS, PIN_EPD_DC, PIN_EPD_RST, PIN_EPD_BUSY));

struct Telemetry {
  float temperature;   // C
  float pressure;      // hPa
  float altitude;      // m
  bool  valid;
};

static bool sensorReady  = false;
static bool displayReady = false;
RTC_DATA_ATTR int currentPage = 0;


static uint8_t readChipId() {
  Wire.beginTransmission(SENSOR_ADDR);
  Wire.write(0xD0);
  if (Wire.endTransmission() != 0) return 0xFF;
  Wire.requestFrom(SENSOR_ADDR, (uint8_t)1);
  return Wire.available() ? Wire.read() : 0xFF;
}

static bool initSensor() {
  Wire.begin(PIN_SDA, PIN_SCL);
  delay(100);

  uint8_t id = readChipId();
  Serial.printf("Sensor chip ID: 0x%02X\n", id);

  if (!sensor.begin(SENSOR_ADDR)) {
    Serial.println("Sensor init failed.");
    return false;
  }

  sensor.setSampling(Adafruit_BMP280::MODE_NORMAL,
                     Adafruit_BMP280::SAMPLING_X2,
                     Adafruit_BMP280::SAMPLING_X16,
                     Adafruit_BMP280::FILTER_X16,
                     Adafruit_BMP280::STANDBY_MS_500);

  Serial.println("Sensor ready.");
  return true;
}

static Telemetry readTelemetry() {
  Telemetry t = {0, 0, 0, false};
  if (!sensorReady) return t;

  t.temperature = sensor.readTemperature();
  t.pressure    = sensor.readPressure() / 100.0f;
  t.altitude    = sensor.readAltitude(SEA_LEVEL_HPA);
  t.valid       = !isnan(t.temperature);
  return t;
}

static bool initDisplay() {
  display.init(0, true, 10, false);
  SPI.end();
  SPI.begin(PIN_EPD_SCK, -1, PIN_EPD_MOSI, PIN_EPD_CS);
  display.setRotation(1);
  display.setFont(&FreeMonoBold9pt7b);
  display.setTextColor(GxEPD_BLACK);
  if (digitalRead(PIN_EPD_BUSY) == HIGH) {
    Serial.println("Display busy line stuck high.");
    return false;
  }

  Serial.println("Display ready.");
  return true;
}

static void renderDashboard(const Telemetry &t) {
  if (!displayReady) return;

  display.setFullWindow();
  display.firstPage();
  do {
    display.fillScreen(GxEPD_WHITE);
    display.drawInvertedBitmap(0, 0, world_map_bitmap, 296, 128, GxEPD_BLACK);

    
    display.fillRect(0, 0, 160, 22, GxEPD_WHITE);
    display.setCursor(4, 16);
    display.print("VOYAGER / ORBIT");

    display.fillRect(0, 106, 296, 22, GxEPD_WHITE);
    display.setCursor(4, 122);
    if (t.valid) {
      display.printf("%.1fC  %.0fhPa  %.0fm", t.temperature, t.pressure, t.altitude);
    } else {
      display.print("SENSOR OFFLINE");
    }
  } while (display.nextPage());
}

//inicio de todo

void setup() {
  pinMode(PIN_LED, OUTPUT);
  digitalWrite(PIN_LED, LOW);

  Serial.begin(115200);
  uint32_t start = millis();
  while (!Serial && millis() - start < 3000) delay(10);

  Serial.println("\nVoyager Panel booting...");

  sensorReady  = initSensor();
  displayReady = initDisplay();

  renderDashboard(readTelemetry());
}

void loop() {
  static uint32_t lastRefresh = 0;
  const uint32_t REFRESH_INTERVAL = 60000;   

  Telemetry t = readTelemetry();

  if (t.valid) {
    Serial.printf("T=%.2fC  P=%.2fhPa  Alt=%.1fm\n",
                  t.temperature, t.pressure, t.altitude);
  }

  if (displayReady && millis() - lastRefresh > REFRESH_INTERVAL) {
    renderDashboard(t);
    lastRefresh = millis();
  }

  digitalWrite(PIN_LED, HIGH);
  delay(100);
  digitalWrite(PIN_LED, LOW);
  delay(1900);
}

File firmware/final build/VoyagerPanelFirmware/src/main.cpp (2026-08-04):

#include <Arduino.h>
#include <GxEPD2_BW.h> // libreria de la waveshare chaval!
#include <Adafruit_BME280.h> // Libreria del sensor
#include <Fonts/FreeMonoBold9pt7b.h>
#include "images.h"


//rtc cuaderno q no olvbida
RTC_DATA_ATTR int currentPage = 0;


#define BTN_NEXT 9
#define BTN_SELECT 10
Adafruit_BME280 bme;
GxEPD2_BW<GxEPD2_290_T94_V2, GxEPD2_290_T94_V2::HEIGHT> display(GxEPD2_290_T94_V2(10, 14, 15, 16));
void sleep() {
  Serial.println("Voyager entrando en hibernacion!");
  display.hibernate();
  esp_sleep_enable_ext0_wakeup(GPIO_NUM_5, 0);
  esp_deep_sleep_start();

}

void setup() {
  Serial.begin(115200);

  esp_sleep_wakeup_cause_t wakeup_reason = esp_sleep_get_wakeup_cause();
  if (wakeup_reason == ESP_SLEEP_WAKEUP_EXT0) {
    currentPage++;
    if (currentPage > 2) currentPage = 0;
  }

  display.init(115200);
  display.setRotation(1);
  display.setFont(&FreeMonoBold9pt7b);
  display.setTextColor(GxEPD_BLACK);

  if( currentPage == 0) {
    showMap();
  } else if (currentPage == 1) {
    showCountdown();
  } else if (currentPage == 2) {
    Wire.begin(12, 13);
    if (bme.begin(0x76)) {
      showWeather();
    } else {
      Serial.println("Error no BME280");
    }
  }
  
  sleep();

  
}

// pages
void showMap() {
  display.firstPage();
  do {
    display.fillScreen(GxEPD_WHITE);
    display.drawInvertedBitmap(0, 0, world_map_bitmap, 296, 128, GxEPD_BLACK);
    display.fillRect(0, 0, 150, 20, GxEPD_WHITE);
    display.setCursor(5, 18);
    display.print("Voyager: ORBIT");
    display.setCursor(5, 120);
    display.print("POS: Ecuador");
  } while (display.nextPage());
}

void showCountdown() {
  display.firstPage();
  do {
    display.fillScreen(GxEPD_WHITE);
    display.setCursor(10, 30);
    display.print("STASIS COUNTDOWN:");
    display.setCursor(10, 80);
    display.print("4 days left");
  } while (display.nextPage());
}
void showWeather() {
  float temp = bme.readTemperature();
  float hum = bme.readHumidity();
  display.firstPage();
  do {
    display.fillScreen(GxEPD_WHITE);
    display.setCursor(10, 30);
    display.print("AMBIENT SENSORS:");
    display.setCursor(10, 75);
    display.printf("TEMP: %.1f C", temp);
    display.setCursor(10, 110);
    display.printf("HUM: %1f %%", hum);
  } while (display.nextPage());
}

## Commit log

2026-04-19 Day One schematic power esp32
2026-04-19 Finished schematic creating pcb
    [voyagerPanel.kicad_pcb, voyagerPanel.kicad_sch]
2026-04-20 PCB almost finished end of day 2
    [voyagerPanel.kicad_pcb, voyagerPanel.kicad_sch]
2026-04-21 finished PCB
    [voyagerPanel.kicad_pcb, voyagerPanel.kicad_sch]
2026-04-23 Firmware finalized!
    [ESP32-S3-MINI-1-N8.STEP, GY-BME280.SLDPRT, Waveshare 2.9 epaper module.step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]
2026-04-24 final push
    [bom_voyager_panel.csv, bom_voyager_panel_links.csv, voyagerPanel.csv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]
2026-04-24 Update README with project details and visuals
    Expanded project description and added sections for schematic, PCB versions, render, BOM, and final notes.
2026-04-24 Update README.md
    BOM i forgot
2026-04-28 Update README with additional PCB images
    Added images for back and front BCU/FCU to README.
2026-04-29 Remade CAD models
    [bom_voyager_final.csv]
2026-08-04 Add BMP280 sensor support and display debugging notes
